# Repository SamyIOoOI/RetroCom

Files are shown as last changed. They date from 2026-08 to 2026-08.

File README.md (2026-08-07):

<h1 align="center">RetroCom</h1>

RetroCom Banner

--------------------------
---------------------------------
## A multiple channel one-to-one (Simultaneous Speech) two-way INTERCOM built around the AT89C52-PI24 MCU // AT89S52-PU24 (8052 Core) with an Embedded FM Radio Model.

### <p align="center">[Main Features](#main-features) **-** [Variations](#variations) **-** [PCB & Schematic](#pcb--schematic-designs) **-** [Assembly Instructions](#-assembly-instructions-) **-** [Case](#case-design) **-** [BOM [Table]](#bill-of-materials) **-** [BOM [CSV]](BOM/BOM.csv) **-** [Gerber Files](/Gerber%20Files/) **-** [BOM[XLSX]](BOM/BOM%20EXCEL.xlsx)</p>

<p align="center">
&nbsp;&nbsp;&nbsp;&nbsp;&nbsp;&nbsp;&nbsp;&nbsp;
</p>

## Main Features

- AT89C52-PI24 MCU per Station. *[Handles Interstation Communication & Interface]*.
- Supports two-way simultaneous speech. No taking turns when talking. RetroCom functions just like a phonecall.
- All stations are connected to main station directly via CAT6 Cables. Distances of 20M (Meters) to 30M are **OK** .
- Switching is done by CD4051 & CD4052 ICs powered with negative & postive 5 V Rails. PreAmped Signals face no distortion.
- Audio undergoes a preamp stage under the TL072 & power amp stage under the LM386.
- The main station has a built in Radio Module. [As of Version 1.0 [WIRED] the radio is restricted to main station with prospects to expand to other stations via HF Radio models in the Wirless versions of RetroCom.]
- All the substations are powered via the Ethernet *(CAT6 if available, other 8 cable variants usable)* No power outlets are needed at the substations.
- Main station supports up to 4 stations in wired mode. Safety measures are applied in the code. No hangs happen when a station is disconnected.
- Code is written in C & compiled with SDCC. Refer to [Station1.hex](station1.hex) & [Station2.hex](station2.hex) for flash-ready code. 

**Be Aware that slight modifications to the code might be required when using different I2C Display modules. Refer to line [35 in main.c](src\main.c) .**

------------------------------------
------------------------------------
## Variations

1- 1.0.0 Wired 2-3-4-Station Package. **[Finished]**:-

- Main station + Station 2 + Station 3 + Station 4
- Code polls for all four stations.
- Main station is connected to the substations via CAT6 Wires.
- Radio control & listen-in is restricted to Station 1 [Main].
- deemed more secure due to the nature of its wired connections.

2- 1.0.0 Wireless 2-30 Station Package [Unfinished]:-
- Planned to dynamically support up to 30 or more stations
- Drops support for CAT6 Wired connections in favor of HF or UHF Radio Transmission.
- Might have security concerns related to signal interception.

-----------------------------------

## PCB & Schematic Designs

The PCB & Schematics were designed in KiCad with a focus on order & accessibility in the case of hand soldering. The RDA5807M [Main Station] is the only SMD Component.``

``All designs follow a two-layer order with the bottom layer functioning as a GND fillzone.``

**== Station 1 [Main Station] [Schematic](KiCad_PCB_Source\RetroCom.kicad_sch) ==**

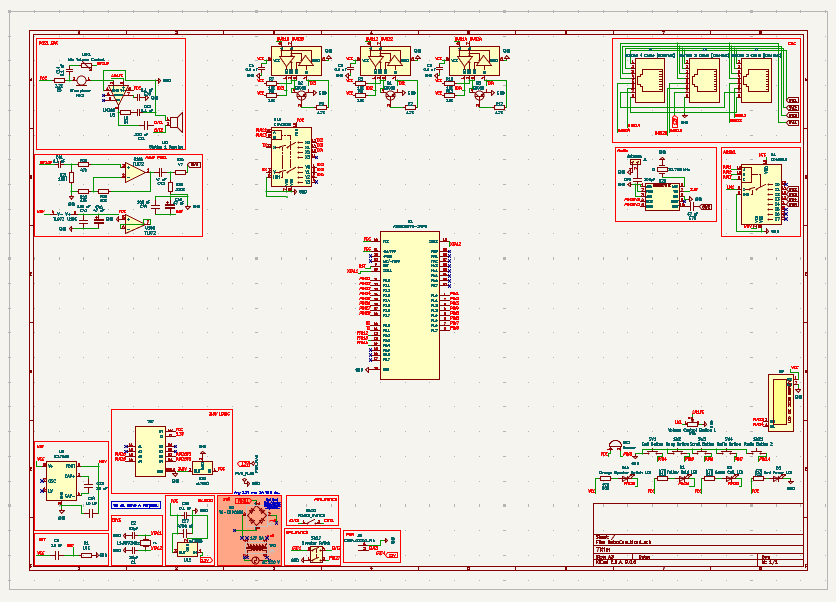
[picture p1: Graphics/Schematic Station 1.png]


**== Station 1 [Main Station] [PCB](KiCad_PCB_Source\RetroCom.kicad_pcb) ==**

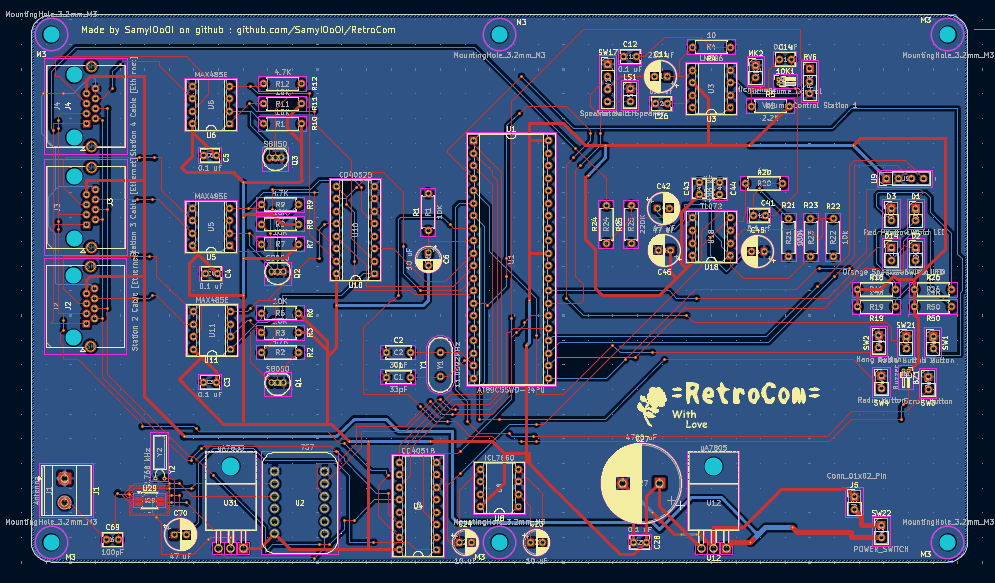
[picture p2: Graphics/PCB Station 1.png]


``3D Model of Board - Uses DIP Sockets Instead of IC Models``

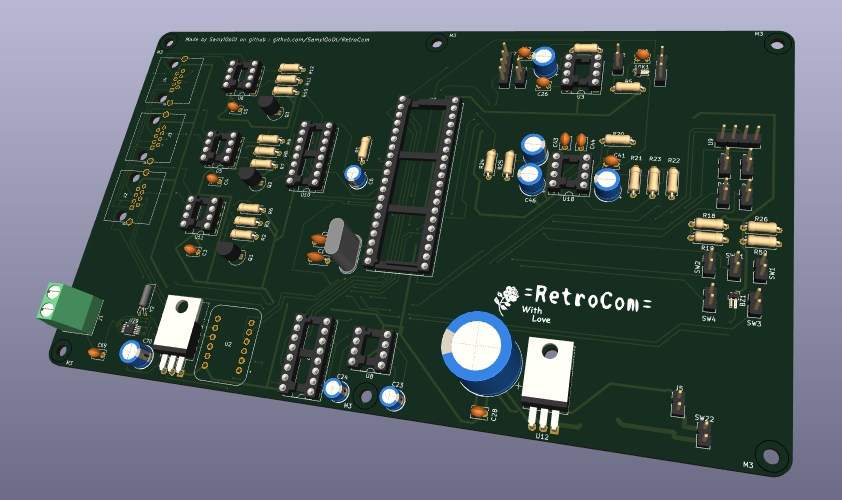
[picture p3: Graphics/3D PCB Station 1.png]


**== Station 2 [Side Station 1] [Schematic](KiCad_PCB_Source\RetroCom_Station2\RetroCom_Station2.kicad_sch) ==**

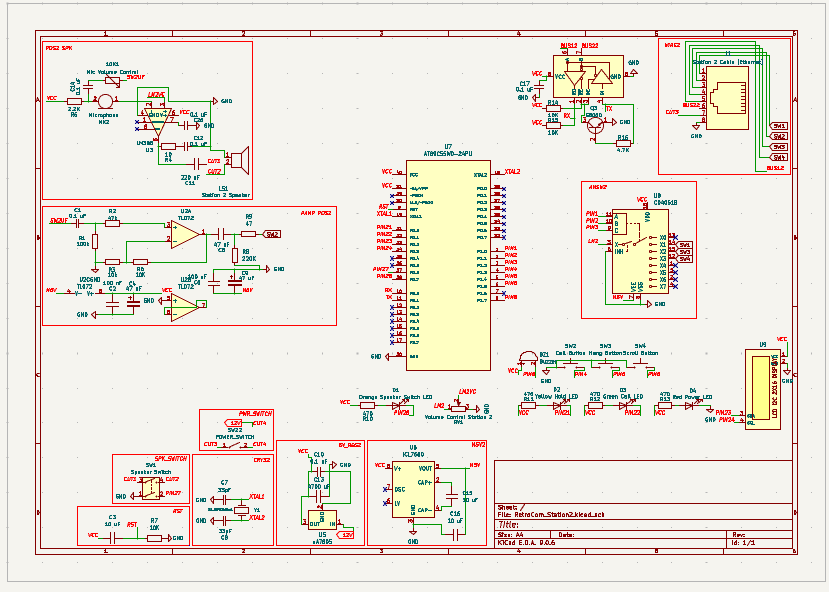
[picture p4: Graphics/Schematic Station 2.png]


**== Station 2 [Side Station 1] [PCB](KiCad_PCB_Source\RetroCom_Station2\RetroCom_Station2.kicad_pcb) ==**

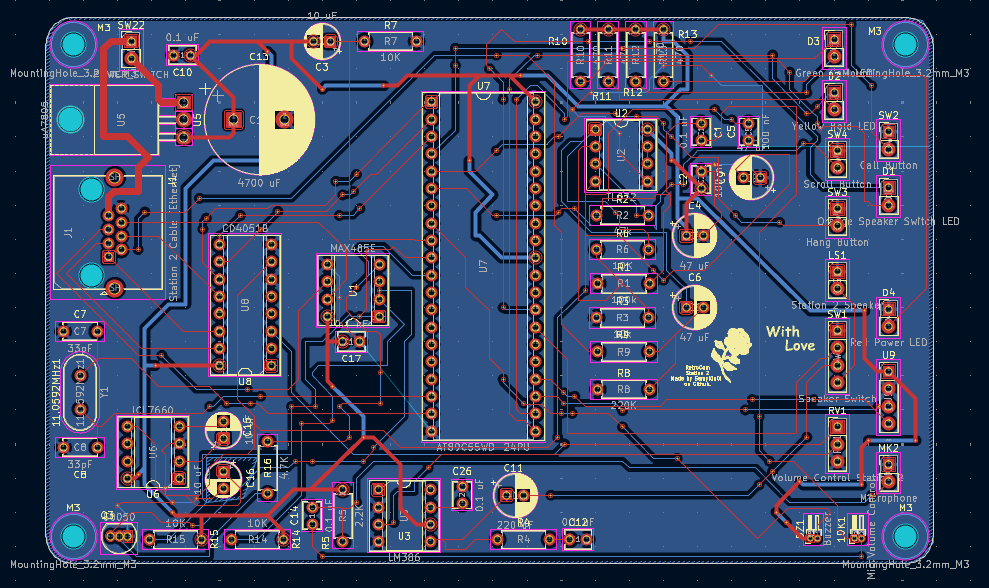
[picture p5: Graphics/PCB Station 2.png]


``3D Model of Board - Uses DIP Sockets Instead of IC Models``

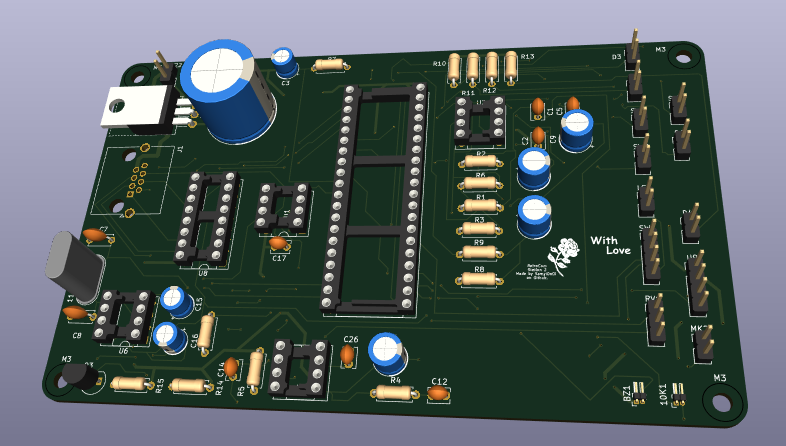
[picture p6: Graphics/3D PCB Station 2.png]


---------------------------------
## Case Design 

The case design was made in fusion with simplicity & practicality in mind.

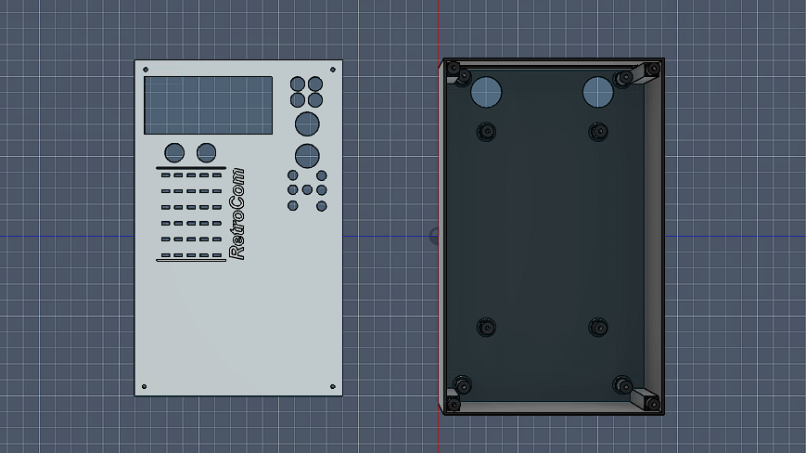
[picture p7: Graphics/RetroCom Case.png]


The design can be accessed via Fusion Share link on your browser through the [link](https://gmail6713823.autodesk360.com/g/shares/SH28cd1QT2badd0ea72b43d7afa1819b979d) provided.

21 x 13 x 5 (cm) are the dimensions of the Case.

---------------------------------
-----------------------------

## = Assembly Instructions =

1- Connecting the PCB & Case

- In the case of **hand-solder** follow the schematic's connections and use the [PCB](Graphics/PCB%20Station%201.png) Design as a reference.
- Use **DIP Sockets** for the ICs (RDA5807M is an exception as it is SMD).
- Connect the ICs & flashed AT89S52s to their respective hand-soldered/printed PCBs.
- Connect the buzzer, speaker, microphone, LEDs, toggle switches, momentary switches & I2C Display through via jumper cables from their respective headers.
- For power, connect half a female jumper wire to the screw terminals of a female DC Socket to wire terminals connector. This can be connected to a **12VDC** 3 & above Amp Wall Adapter.
- Solder the RJ45 Houses in their locations, run CAT6 Cables from each sub-station to main station. 
- For the case, if using the printed design, connect the board to its respective mounting holes via M3 Screws [8mm - 10mm]. 
- Each printed case design has eight board mounting holes to suit both board sizes (Side Stations & Main Station).
- Place the interface components on the surface panel of the case, run jumper cables to the board below. Use the four corner bound M3 screw holes for holding the panel on the bottom case piece. Run the outgoing cables through the back panel.

2- Flashing the code (.hex) files into the AT89S52 Chip.

- Place the AT89 on a breadboard & build the  crystal and reset circuits. Refer to the [Schematic](Graphics/Schematic%20Station%202.png) for details. Look for labels "**CRYS**" & "**RST**".
- Plug the USBasp into you pc/laptop USB port & select it in Zadig's drop-down menu. Install libusb-win32 or libusbK.
- Connect the ISP lines MOSI, MISO, SCK, RESET & GND. EA pin must be connected to VCC. Do not power the circuit before completion.
- Power the circuit through either: A- External 5V Supply B- USBasp's 5V Pinout.
- Use ProgISP to flash the chip. Select AT89S52 from the drop-down menu.

**[ProgISP](https://www.phippselectronics.com/support/prog-isp-software/) Software & [Zadig](https://zadig.akeo.ie/#) Drivers Installer are required to flash the chips.**

## Bill of Materials

| **Part Name** | **Quantity** | **Price** | **Link** |
|---|---|---|---|
| **33pF Capacitor** | 4.00 |  EGP 2.00 | https://makerselectronics.com/product/ceramic-capacitor-33pf-50v/ |
| **10 uF cap** | 6.00 |  EGP 6.00 | https://www.ram-e-shop.com/shop/c-10u25v-capacitor-10uf-25v-6095 |
| **220 uF Cap** | 2.00 |  EGP 2.00 | https://www.ram-e-shop.com/shop/c-220u16v-capacitor-220uf-16v-5654 |
| **4700 uF cap** | 2.00 |  EGP 12.00 | https://www.ram-e-shop.com/shop/c-4700u25v-capacitor-4700uf-25v-6079 |
| **47 uF cap** | 7.00 |  EGP 7.00 | https://makerselectronics.com/product/capacitor-47uf-50v/ |
| **100 nF Cap** | 18.00 |  EGP 13.50 | https://www.ram-e-shop.com/shop/c-pf-104-ceramic-capacitor-pf104-100nf-25v-6240 |
| **100 pF Cap** | 1.00 |  EGP 0.50 | https://makerselectronics.com/product/ceramic-capacitor-100pf-50v/ |
| **Yellow LED  10mm** | 2.00 |  EGP 6.00 | https://makerselectronics.com/product/yellow-led-transparent-10mm/ |
| **Green LED  10mm** | 2.00 |  EGP 6.00 | https://makerselectronics.com/product/green-led-10mm-transparent/ |
| **Red LED  10mm** | 2.00 |  EGP 6.00 | https://makerselectronics.com/product/red-led-transparent-10mm/ |
| **Orange LED  10mm** | 2.00 |  EGP 6.00 | https://makerselectronics.com/product/orange-led-10mm-transparent/ |
| **RJ8-P-PCB (RJ45 8P8C Plastic Housing)** | 5.00 |  EGP 25.00 | https://www.ram-e-shop.com/shop/rj8-p-pcb-rj45-8-pin-connector-on-pcb-plastic-housing-5749 |
| **10K R** | 14.00 |  EGP 4.00 | https://www.ram-e-shop.com/shop/carbon-resistance-1-4w-price-per-4-resistors-9506#attr=314 |
| **2.2K R** | 2.00 |  EGP 0.10 | https://makerselectronics.com/product/carbon-resistor-2-2k%cf%89-0-125w-through-hole/ |
| **10 R** | 2.00 |  EGP 1.50 | https://makerselectronics.com/product/carbon-resistor-10%cf%89-0-25w-through-hole/ |
| **470 R** | 8.00 |  EGP 2.00 | https://www.ram-e-shop.com/shop/carbon-resistance-1-4w-price-per-4-resistors-9506#attr=307 |
| **47k R** | 1.00 |  EGP 1.50 | https://makerselectronics.com/product/carbon-resistor-47k%cf%89-0-25w/ |
| **100k R** | 2.00 |  EGP 1.00 | https://www.ram-e-shop.com/shop/carbon-resistance-1-4w-price-per-4-resistors-9506#attr=317 |
| **47 R** | 2.00 |  EGP 0.20 | https://makerselectronics.com/product/carbon-resistor-47%cf%89-0-125w-through-hole/ |
| **220K R** | 2.00 |  EGP 1.50 | https://makerselectronics.com/product/carbon-resistor-220k%cf%89-0-25w-through-hole/ |
| **4.7K R** | 4.00 |  EGP 1.50 | https://makerselectronics.com/product/carbon-resistor-4-7k-0-25w/ |
| **C8050** | 4.00 |  EGP 3.00 | https://www.ram-e-shop.com/shop/c8050-c8050-6050 |
| **11.0592MHz Crystal** | 2.00 |  EGP 8.00 | https://www.ram-e-shop.com/shop/o-11-0592mhz-crystal-oscillator-11-0592-mhz-5668 |
| **32.768 kHz Crystal** | 1.00 |  EGP 3.00 | https://www.ram-e-shop.com/shop/o-32-768khz-crystal-oscillator-32-768-khz-5880 |
| **PIN Headers x40 Male** | 2.00 |  EGP 6.00 | https://makerselectronics.com/product/pin-headers-male-2-54mm-40-pin-straight-black-11mm/ |
| **PIN Headers x40 Female** | 2.00 |  EGP 10.00 | https://makerselectronics.com/product/pin-headers-female-2-54mm-40-pin/ |
| **Speakers 8 ohm 0.25 watts** | 2.00 |  EGP 20.00 | https://makerselectronics.com/product/speaker-8%cf%89-0-25w-o-29mm/ |
| **Condenser Microphone** | 2.00 |  EGP 12.00 | https://makerselectronics.com/product/condenser-microphone-2-pins/ |
| **I2C LCD 2x16 Modules** | 2.00 |  EGP 290.00 | https://www.ram-e-shop.com/shop/lcd-i2c-2x16-blue-iic-i2c-1602-serial-character-lcd-2x16-display-8884 |
| **4 Pin Toggle Switch DSPT** | 2.00 |  EGP 80.00 | https://makerselectronics.com/product/toggle-switch-4-pins-15a-e-ten1221-o/ |
| **2 Pin Toggle Switch SPST** | 2.00 |  EGP 40.00 | https://makerselectronics.com/product/toggle-switch-on-off-2-pin-2a-12mm/ |
| **Momentary Toggle presses/switches 8** | 8.00 |  EGP 52.00 | https://makerselectronics.com/product/push-button-switch-on-off-2pin/ |
| **Buzzers** | 2.00 |  EGP 50.00 | https://www.ram-e-shop.com/shop/buzzer12v-big-black-buzzer-big-size-3-24v-piezo-electronic-alarm-6122 |
| **PCB 13x25 cm2 Dotted Holes** | 2.00 |  EGP 97.00 | https://www.ram-e-shop.com/shop/pcb23-holes-13x25-pcb-13x25-cm2-dots-holes-sku-pcb23-6681 |
| **Jumper Wire Cables Male to Male [40 Wires]** | 2.00 |  EGP 70.00 | https://www.ram-e-shop.com/shop/ph61-mm-20cm-ph61-20cm-male-to-male-40-jumper-wires-set-7094 |
| **Jumper Wire Cables Female to Female [40 Wires]** | 1.00 |  EGP 35.00 | https://www.ram-e-shop.com/shop/ph62-ff-20cm-ph62-20cm-female-to-female-40-jumper-wires-set-7189 |
| **Jumper Wire Cables Male to Female [40 Wires]** | 2.00 |  EGP 70.00 | https://www.ram-e-shop.com/shop/ph60-mf-20cm-ph60-20cm-male-to-female-40-jumper-wires-set-7066 |
| **Solder Wire** | 1.00 |  EGP 210.00 | https://makerselectronics.com/product/soldering-wire-100gm-alloy70-30-made/ |
| **Soldering Iron** | 1.00 |  EGP 195.00 | https://www.ram-e-shop.com/shop/se860-suoer-se860-60w-basic-soldering-iron-ct-360-5600 |
| **Soldering Iron Stand** | 1.00 |  EGP 45.00 | https://makerselectronics.com/product/no-218-soldering-iron-stand/ |
| **Soldering Paste** | 1.00 |  EGP 25.00 | https://makerselectronics.com/product/yx-18-flux-soldering-paste/?attribute_size=50g |
| **Fares USBasp AVR programmer** | 1.00 |  EGP 175.00 | https://www.ram-e-shop.com/shop/prog-avr-fares-fares-usbasp-avr-programmer-8325 |
| **20 Meter CAT6 Cable** | 1.00 |  EGP 165.00 | https://makerselectronics.com/product/zlink-cable-cat6-ethernet-patch-cord/ |
| **12 VDC Wall Power Adapter** | 1.00 |  EGP 135.00 | https://www.ram-e-shop.com/shop/adapter-fixed-12v-3a-wall-power-adapter-12vdc-3a-high-quality-adapter-5573 |
| **Female DC Jack Adapter with Terminal Block** | 1.00 |  EGP 7.00 | https://makerselectronics.com/product/female-dc-jack-adapter-terminals/ |
| **AT89S52-PU24** | 2.00 |  EGP 170.00 | https://makerselectronics.com/product/at89s52-24pu-8kb-4v5-5v-256byte-24/ |
| **IC Socket DIP-40** | 2.00 |  EGP 10.00 | https://www.ram-e-shop.com/shop/n20-20-ic-socket-n20-20-base-40-pin-5902 |
| **IC Socket DIP-16** | 3.00 |  EGP 5.25 | https://makerselectronics.com/product/ic-socket-88-base-16-pin/ |
| **CD4051** | 2.00 |  EGP 30.00 | https://www.ram-e-shop.com/shop/4051-ic-4051-single-8-channel-multiplexer-demultiplexer-5551 |
| **CD4052BE** | 1.00 |  EGP 9.00 | https://makerselectronics.com/product/cd4052be-dual-4-channel-analog/ |
| **IC Socket DIP-8** | 10.00 |  EGP 7.50 | https://www.ram-e-shop.com/shop/n4-4-ic-socket-n4-4-base-8-pin-5864 |
| **TL072CN** | 2.00 |  EGP 34.00 | https://www.ram-e-shop.com/shop/tl072-tl072cn-5722 |
| **LM386N** | 2.00 |  EGP 12.00 | https://www.ram-e-shop.com/shop/lm386-lm386n-5927 |
| **ICL7660** | 2.00 |  EGP 102.60 | https://uge-one.com/product/icl7660/ |
| **MAX485CPA+** | 4.00 |  EGP 72.00 | https://makerselectronics.com/product/ic-max485cpa-low-power-transceiver-dip-8/ |
| **LM7805 Regulator** | 2.00 |  EGP 10.00 | https://makerselectronics.com/product/lm7805-voltage-regulator-to-220-5v/ |
| **LD33CV Regulator** | 1.00 |  EGP 20.00 | https://www.ram-e-shop.com/shop/ld1117v33-ld1117v33-ld33cv-6735 |
| **TO-220 Regulator Heat Sink** | 3.00 |  EGP 10.50 | https://www.ram-e-shop.com/shop/hs2-aluminum-heatsink-hs-2-size-25x14x10-mm-5981 |
| **Logic level Converter Module** | 1.00 |  EGP 28.50 | https://uge-one.com/product/bi-directional-4-way-level-conversion-module/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 |
| **Metal Potentiometer 10K? 3-Pin** | 2.00 |  EGP 11.00 | https://makerselectronics.com/product/metal-potentiometer-10k%cf%89-3-pin/ |
| **RDA5807M** | 1.00 |  EGP 55.00 | https://uge-one.com/product/rda5807m-fm-radio-receiver-smd-ic-msop1 |
| **** | |  EGP 2,495.65  | |
| **** | | | |
| **Note: Most resistors come in pack of 10s - 4s**  | | | |
| **** | | | |
| **Shipping: RAM** | |  EGP 105.00 | |
| **Shipping: Makers Electronics** | 80 - 75 |  EGP 80.00 | |
| **Shipping: UGE Electronics** | |  EGP 188.10 | |
| **VAT: UGE Electronics** | |  EGP 45.95 | |
| **** | |  EGP 419.05 | |
| **** | | | |
| **** | |  EGP 2,914.70  | |

## Credits

[Kicad](https://www.kicad.org/) : Schematic & PCB designs

[Autodesk Fusion](https://www.autodesk.com/ae/products/fusion-360/overview) : 3D Case Design

[Visual Studio Code](https://code.visualstudio.com/) : Logic Code Design

[Embedded IDE For VSCode](https://em-ide.com/en/) : Compiling C files into .hex format

[Notaroomba Cyberboard](https://github.com/notaroomba/cyberboard#key-features) : Inspired readme format

[tableconvert.com](https://tableconvert.com/excel-to-markdown) : Turned my xlsx table to markdown format

## Licence

Made by SamyIOoOI on github under the GPL-3.0 Licence.

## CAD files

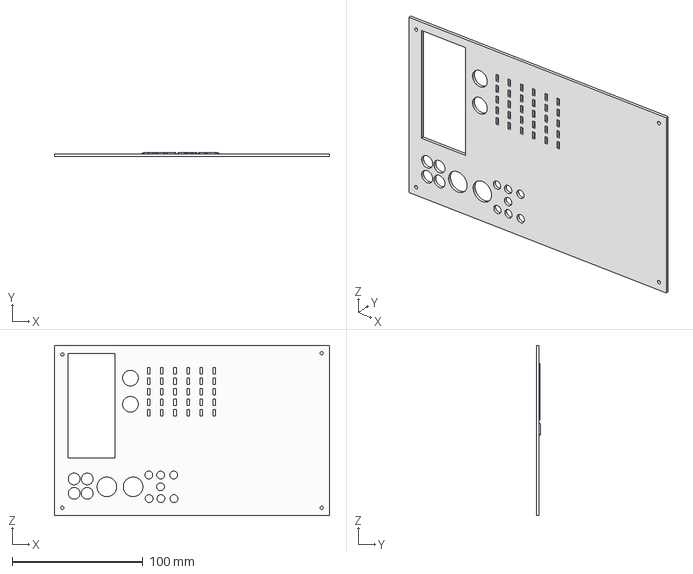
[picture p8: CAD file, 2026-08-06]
Fusion_Case_Cad/RetroCom Case CAD/RetroCom Case Top.step
210.0 x 3.00 x 130.0 mm

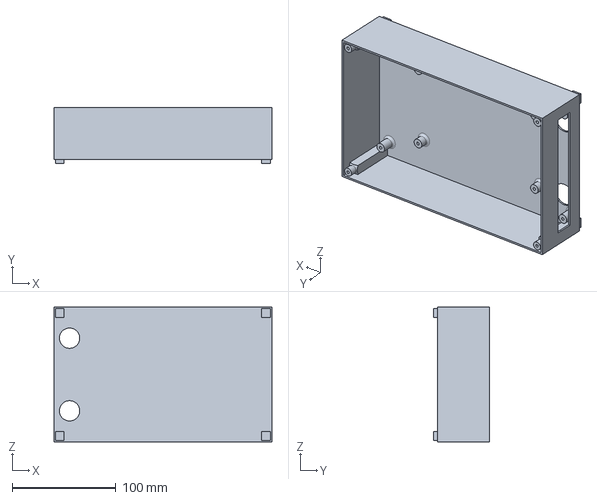
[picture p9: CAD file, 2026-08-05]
Fusion_Case_Cad/RetroCom Case CAD/RetroCom Case Bottom.step
210.0 x 53.5 x 130.0 mm

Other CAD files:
Fusion_Case_Cad/RetroCom Case CAD/RetroCom Case Bottom.f3d
Fusion_Case_Cad/RetroCom Case CAD/RetroCom Case Bottom.stl
Fusion_Case_Cad/RetroCom Case CAD/RetroCom Case Top.f3d
Fusion_Case_Cad/RetroCom Case CAD/RetroCom Case Top.stl

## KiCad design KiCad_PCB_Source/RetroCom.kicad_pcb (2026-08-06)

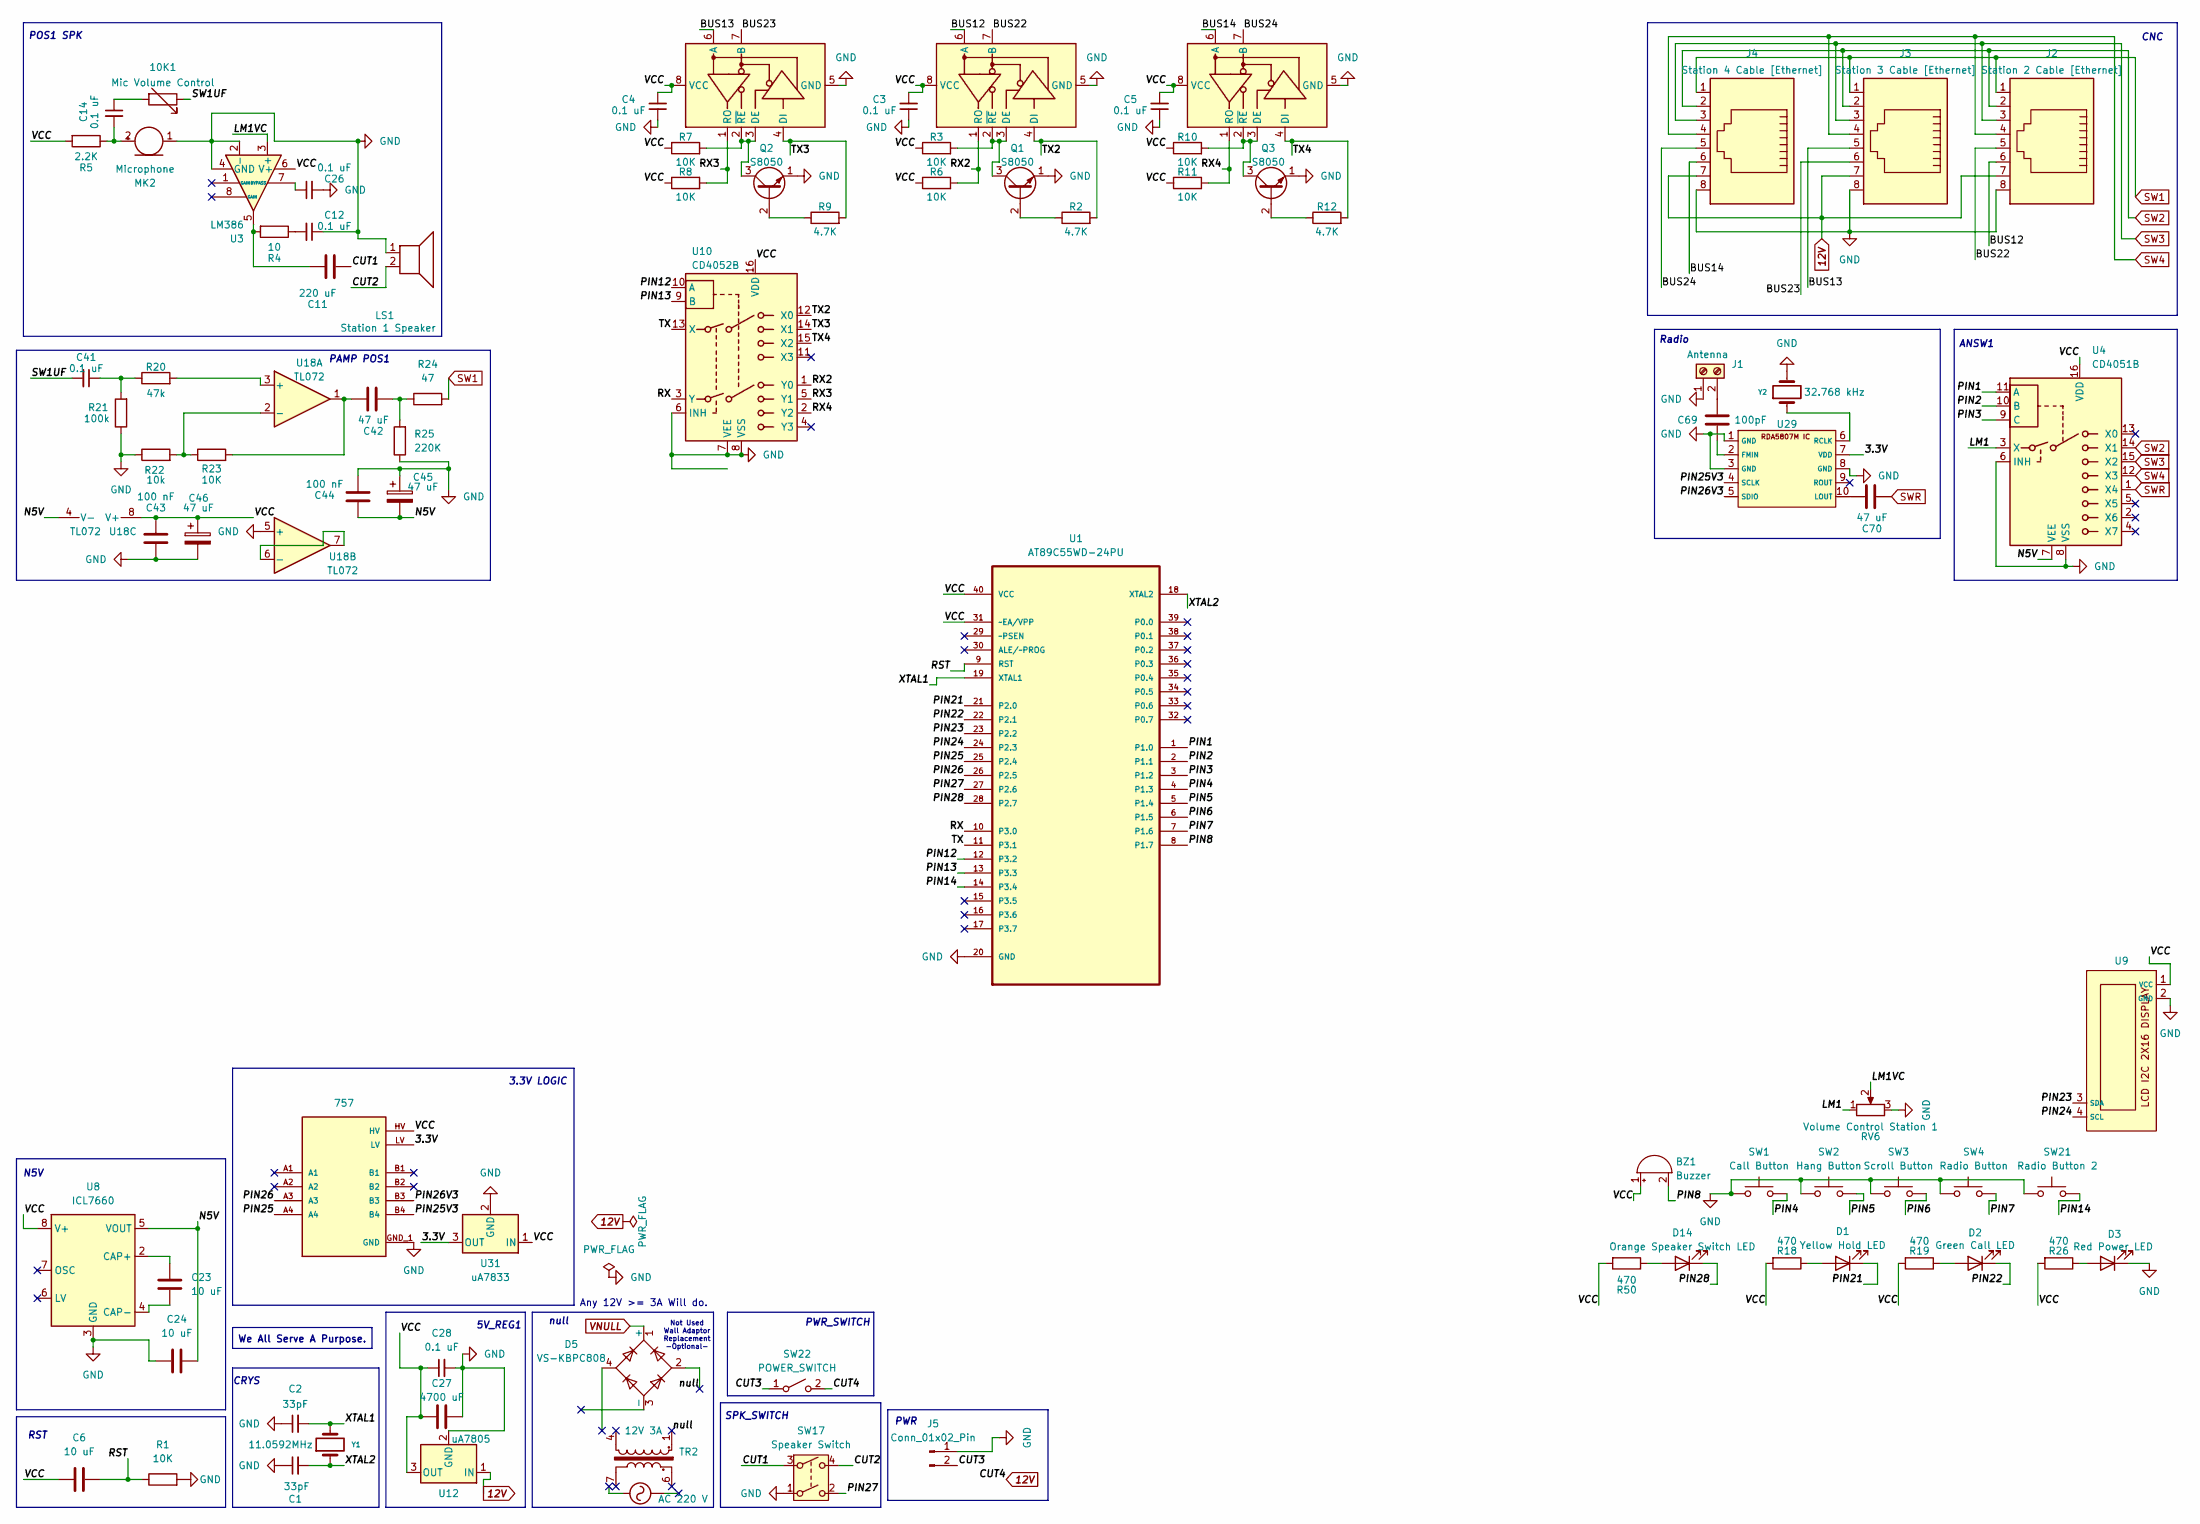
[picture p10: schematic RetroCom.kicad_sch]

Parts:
10K1: Mic Volume Control; PinHeader_1x02_P1.00mm_Horizontal
BZ1: Buzzer; PinHeader_1x02_P1.00mm_Horizontal
C1, C2: 33pF; C_Disc_D5.0mm_W2.5mm_P5.00mm
C3, C4, C5, C12, C14, C26, C28, C41: 0.1 uF; C_Disc_D3.8mm_W2.6mm_P2.50mm
C6, C23, C24: 10 uF; CP_Radial_D5.0mm_P2.50mm
C11: 220 uF; CP_Radial_D6.3mm_P2.50mm
C27: 4700 uF; CP_Radial_D16.0mm_P7.50mm
C42, C45, C46, C70: 47 uF; CP_Radial_D6.3mm_P2.50mm
C43, C44: 100 nF; C_Disc_D3.8mm_W2.6mm_P2.50mm
C69: 100pF; C_Disc_D3.8mm_W2.6mm_P2.50mm
D1: Yellow Hold LED; PinHeader_1x02_P2.54mm_Vertical
D2: Green Call LED; PinHeader_1x02_P2.54mm_Vertical
D3: Red Power LED; PinHeader_1x02_P2.54mm_Vertical
D5: VS-KBPC808; Diode_Bridge_Vishay_KBPC6
D14: Orange Speaker Switch LED; PinHeader_1x02_P2.54mm_Vertical
J1: Antenna; TerminalBlock_Phoenix_MKDS-1,5-2_1x02_P5.00mm_Horizontal
J2: Station 2 Cable [Ethernet]; RJ45_Amphenol_RJHSE5380
J3: Station 3 Cable [Ethernet]; RJ45_Amphenol_RJHSE5380
J4: Station 4 Cable [Ethernet]; RJ45_Amphenol_RJHSE5380
J5: Conn_01x02_Pin; PinHeader_1x02_P2.54mm_Vertical
LS1: Station 1 Speaker; PinHeader_1x02_P2.54mm_Vertical
MK2: Microphone; PinHeader_1x02_P2.54mm_Vertical
Q1, Q2, Q3: S8050; TO-92_Inline
R1, R3, R6, R7, R8, R10, R11, R23: 10K; R_Axial_DIN0207_L6.3mm_D2.5mm_P7.62mm_Horizontal
R2, R9, R12: 4.7K; R_Axial_DIN0207_L6.3mm_D2.5mm_P7.62mm_Horizontal
R4: 10; R_Axial_DIN0207_L6.3mm_D2.5mm_P7.62mm_Horizontal
R5: 2.2K; R_Axial_DIN0207_L6.3mm_D2.5mm_P7.62mm_Horizontal
R18, R19, R26, R50: 470; R_Axial_DIN0207_L6.3mm_D2.5mm_P7.62mm_Horizontal
R20: 47k; R_Axial_DIN0207_L6.3mm_D2.5mm_P7.62mm_Horizontal
R21: 100k; R_Axial_DIN0207_L6.3mm_D2.5mm_P7.62mm_Horizontal
R22: 10k; R_Axial_DIN0207_L6.3mm_D2.5mm_P7.62mm_Horizontal
R24: 47; R_Axial_DIN0207_L6.3mm_D2.5mm_P7.62mm_Horizontal
R25: 220K; R_Axial_DIN0207_L6.3mm_D2.5mm_P7.62mm_Horizontal
RV6: Volume Control Station 1; PinHeader_1x03_P2.54mm_Vertical
SW1: Call Button; PinHeader_1x02_P2.54mm_Vertical
SW2: Hang Button; PinHeader_1x02_P2.54mm_Vertical
SW3: Scroll Button; PinHeader_1x02_P2.54mm_Vertical
SW4: Radio Button; PinHeader_1x02_P2.54mm_Vertical
SW17: Speaker Switch; PinHeader_1x04_P2.54mm_Vertical
SW21: Radio Button 2; PinHeader_1x02_P2.54mm_Vertical
SW22: POWER_SWITCH; PinHeader_1x02_P2.54mm_Vertical
TR2: 12V 3A; FanPinHeader_1x04_P2.54mm_Vertical
U1: AT89C55WD-24PU; DIP-40_W15.24mm_Socket; MPN AT89C55WD-24PU
U2: 757; MODULE_757; PARTREV N/A
U3: LM386; DIP-8_W7.62mm_Socket
U4: CD4051B; DIP-16_W7.62mm_Socket
U5, U6, U11: MAX485E; DIP-8_W7.62mm_Socket
U8: ICL7660; DIP-8_W7.62mm_Socket
U9: PinHeader_1x04_P2.54mm_Vertical
U10: CD4052B; DIP-16_W7.62mm_Socket
U12: uA7805; TO-220-3_Horizontal_TabUp
U18: TL072; DIP-8_W7.62mm_Socket
U29: MSOP-10_3x3mm_P0.5mm
U31: uA7833; TO-220-3_Horizontal_TabUp
Y1: 11.0592MHz; Crystal_HC49-U_Vertical
Y2: 32.768 kHz; Crystal_C26-LF_D2.1mm_L6.5mm_Horizontal

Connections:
12V: J2.7, J3.7, J4.7, SW22.2 (B), U12.1 (IN)
/3.3V: U2.LV, U29.7 (VDD), U31.3 (OUT)
/BUS12: J2.6, U11.6 (A)
/BUS13: J3.5, U5.6 (A)
/BUS14: J4.6, U6.6 (A)
/BUS22: J2.5, U11.7 (B)
/BUS23: J3.6, U5.7 (B)
/BUS24: J4.5, U6.7 (B)
/CUT1: C11.2, SW17.3
/CUT2: LS1.2, SW17.4
/CUT3: J5.2, SW22.1 (A)
/LM1: RV6.1, U4.3 (X)
/LM1VC: RV6.2, U3.3 (+)
/N5V: C24.1, C44.2, C45.2, U4.7 (VEE), U8.5 (VOUT), U18.4 (V-)
/PIN1: U1.1 (P1.0), U4.11 (A)
/PIN2: U1.2 (P1.1), U4.10 (B)
/PIN3: U1.3 (P1.2), U4.9 (C)
/PIN4: SW1.2, U1.4 (P1.3)
/PIN5: SW2.2, U1.5 (P1.4)
/PIN6: SW3.2, U1.6 (P1.5)
/PIN7: SW4.2, U1.7 (P1.6)
/PIN8: BZ1.2 (-), U1.8 (P1.7)
/PIN12: U1.12 (P3.2), U10.10 (A)
/PIN13: U1.13 (P3.3), U10.9 (B)
/PIN14: SW21.2, U1.14 (P3.4)
/PIN21: D1.1 (K), U1.21 (P2.0)
/PIN22: D2.1 (K), U1.22 (P2.1)
/PIN23: U1.23 (P2.2), U9.3 (SDA)
/PIN24: U1.24 (P2.3), U9.4 (SCL)
/PIN25: U1.25 (P2.4), U2.A4
/PIN25V3: U2.B4, U29.4 (SCLK)
/PIN26: U1.26 (P2.5), U2.A3
/PIN26V3: U2.B3, U29.5 (SDIO)
/PIN27: SW17.2, U1.27 (P2.6)
/PIN28: D14.1 (K), U1.28 (P2.7)
/RST: C6.1, R1.1, U1.9 (RST)
/RX: U1.10 (P3.0), U10.3 (Y)
/RX2: R6.2, U10.1 (Y0), U11.1 (RO)
/RX3: R8.2, U5.1 (RO), U10.5 (Y1)
/RX4: R11.2, U6.1 (RO), U10.2 (Y2)
/SW1UF: 10K1.1, C41.2
/TX: U1.11 (P3.1), U10.13 (X)
/TX2: R2.2, U10.12 (X0), U11.4 (DI)
/TX3: R9.2, U5.4 (DI), U10.14 (X1)
/TX4: R12.2, U6.4 (DI), U10.15 (X2)
/VCC: BZ1.1 (+), C3.2, C4.2, C5.2, C6.2, C27.1, C28.1, C43.1, C46.1, R3.1, R5.2, R6.1, R7.1, R8.1, R10.1, R11.1, R18.2, R19.2, R26.2, R50.2, U1.31 (~EA/VPP), U1.40 (VCC), U2.HV, U3.6 (V+), U4.16 (VDD), U5.8 (VCC), U6.8 (VCC), U8.8 (V+), U9.1 (VCC), U10.16 (VDD), U11.8 (VCC), U12.3 (OUT), U18.8 (V+), U31.1 (IN)
/XTAL1: C2.2, U1.19 (XTAL1), Y1.2
/XTAL2: C1.2, U1.18 (XTAL2), Y1.1
GND: C1.1, C2.1, C3.1, C4.1, C5.1, C12.1, C24.2, C26.2, C27.2, C28.2, C43.2, C44.1, C45.1, C46.2, D3.1 (K), J1.1, J2.8, J3.8, J4.8, J5.1, LS1.1, MK2.1 (-), Q1.1 (E), Q2.1 (E), Q3.1 (E), R1.2, R21.1, R22.1, R25.1, RV6.3, SW1.1, SW2.1, SW3.1, SW4.1, SW17.1, SW21.1, U1.20 (GND), U2.GND_1 (GND), U2.GND_2 (GND), U3.2 (-), U3.4 (GND), U4.6 (INH), U4.8 (VSS), U5.5 (GND), U6.5 (GND), U8.3 (GND), U9.2 (GND), U10.6 (INH), U10.7 (VEE), U10.8 (VSS), U11.5 (GND), U12.2 (GND), U18.5 (+), U29.1 (GND), U29.3 (GND), U29.8 (GND), U31.2 (GND), Y2.2
unnamed: 10K1.2, C14.1
unnamed: C11.1, R4.2, U3.5
unnamed: C12.2, R4.1
unnamed: C41.1, R20.1, R21.2
unnamed: C42.1, R23.2, U18.1
unnamed: C42.2, R24.1, R25.2
unnamed: D1.2 (A), R18.1
unnamed: D2.2 (A), R19.1
unnamed: D3.2 (A), R26.1
unnamed: D5.2, TR2.1
unnamed: D14.2 (A), R50.1
unnamed: C69.1, J1.2
unnamed: C14.2, MK2.2 (+), R5.1
unnamed: Q1.2 (B), R2.1
unnamed: Q1.3 (C), R3.2, U11.2 (~RE), U11.3 (DE)
unnamed: Q2.2 (B), R9.1
unnamed: Q2.3 (C), R7.2, U5.2 (~RE), U5.3 (DE)
unnamed: Q3.2 (B), R12.1
unnamed: Q3.3 (C), R10.2, U6.2 (~RE), U6.3 (DE)
unnamed: C26.1, U3.7 (BYPASS)
unnamed: C23.1, U8.2 (CAP+)
unnamed: C23.2, U8.4 (CAP-)
unnamed: R20.2, U18.3 (+)
unnamed: R22.2, R23.1, U18.2 (-)
unnamed: U18.6 (-), U18.7
unnamed: C69.2, U29.2 (FMIN)
unnamed: C70.1, U29.10 (LOUT)
unnamed: U29.6 (RCLK), Y2.1
SW1: J2.1, J3.1, J4.1, R24.2
SW2: J2.2, J3.2, J4.2, U4.14 (X1)
SW3: J2.3, J3.3, J4.3, U4.15 (X2)
SW4: J2.4, J3.4, J4.4, U4.12 (X3)
SWR: C70.2, U4.1 (X4)

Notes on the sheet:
3.3V LOGIC
We All Serve A Purpose.
Radio
CNC
POS1 SPK
5V_REG1
PWR
PWR_SWITCH
RST
Not Used Wall Adaptor Replacement -Optional-
ANSW1
SPK_SWITCH
N5V
CRYS
PAMP POS1
null
Any 12V >= 3A Will do.

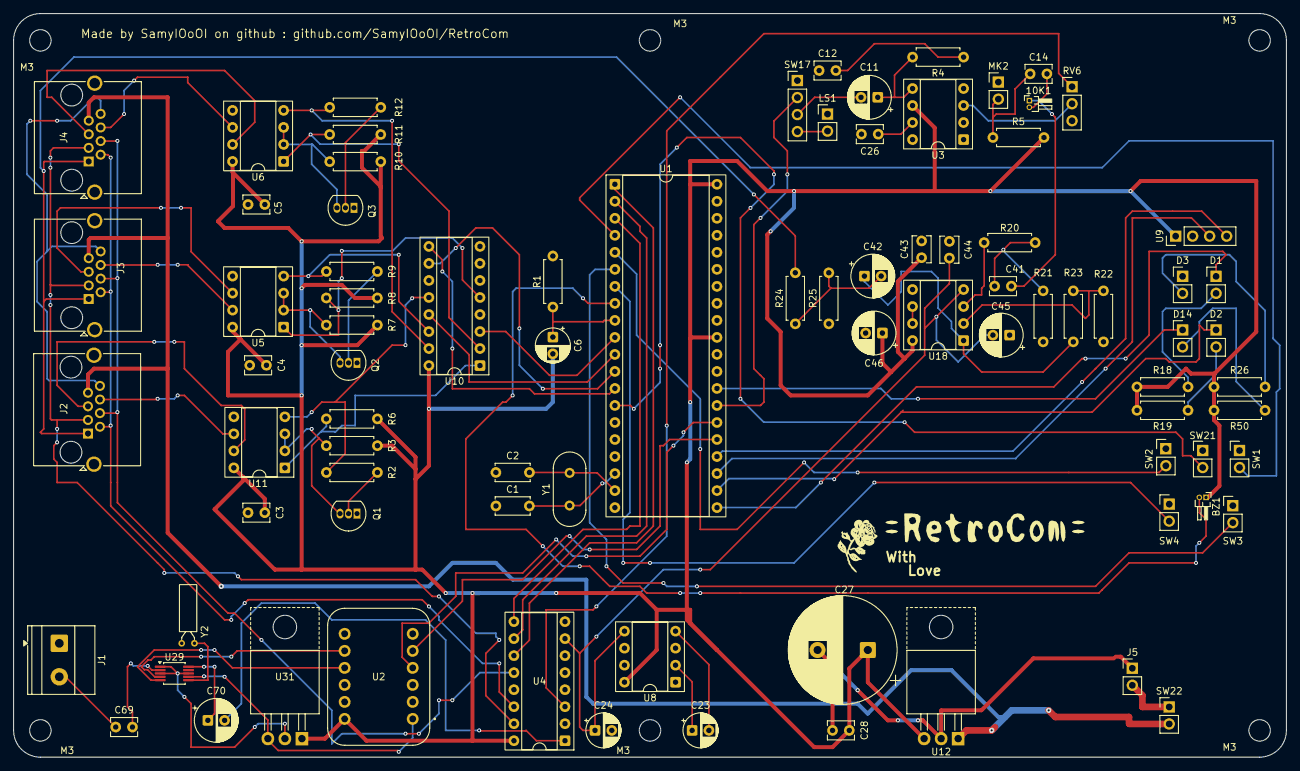
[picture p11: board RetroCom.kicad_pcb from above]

Board: 2 copper layers, 190.0 x 111.0 mm, 90 parts (0 on the bottom side), 81 nets.

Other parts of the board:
M3, M3#2, M3#3, M3#4, M3#5, M3#6: MountingHole_3.2mm_M3

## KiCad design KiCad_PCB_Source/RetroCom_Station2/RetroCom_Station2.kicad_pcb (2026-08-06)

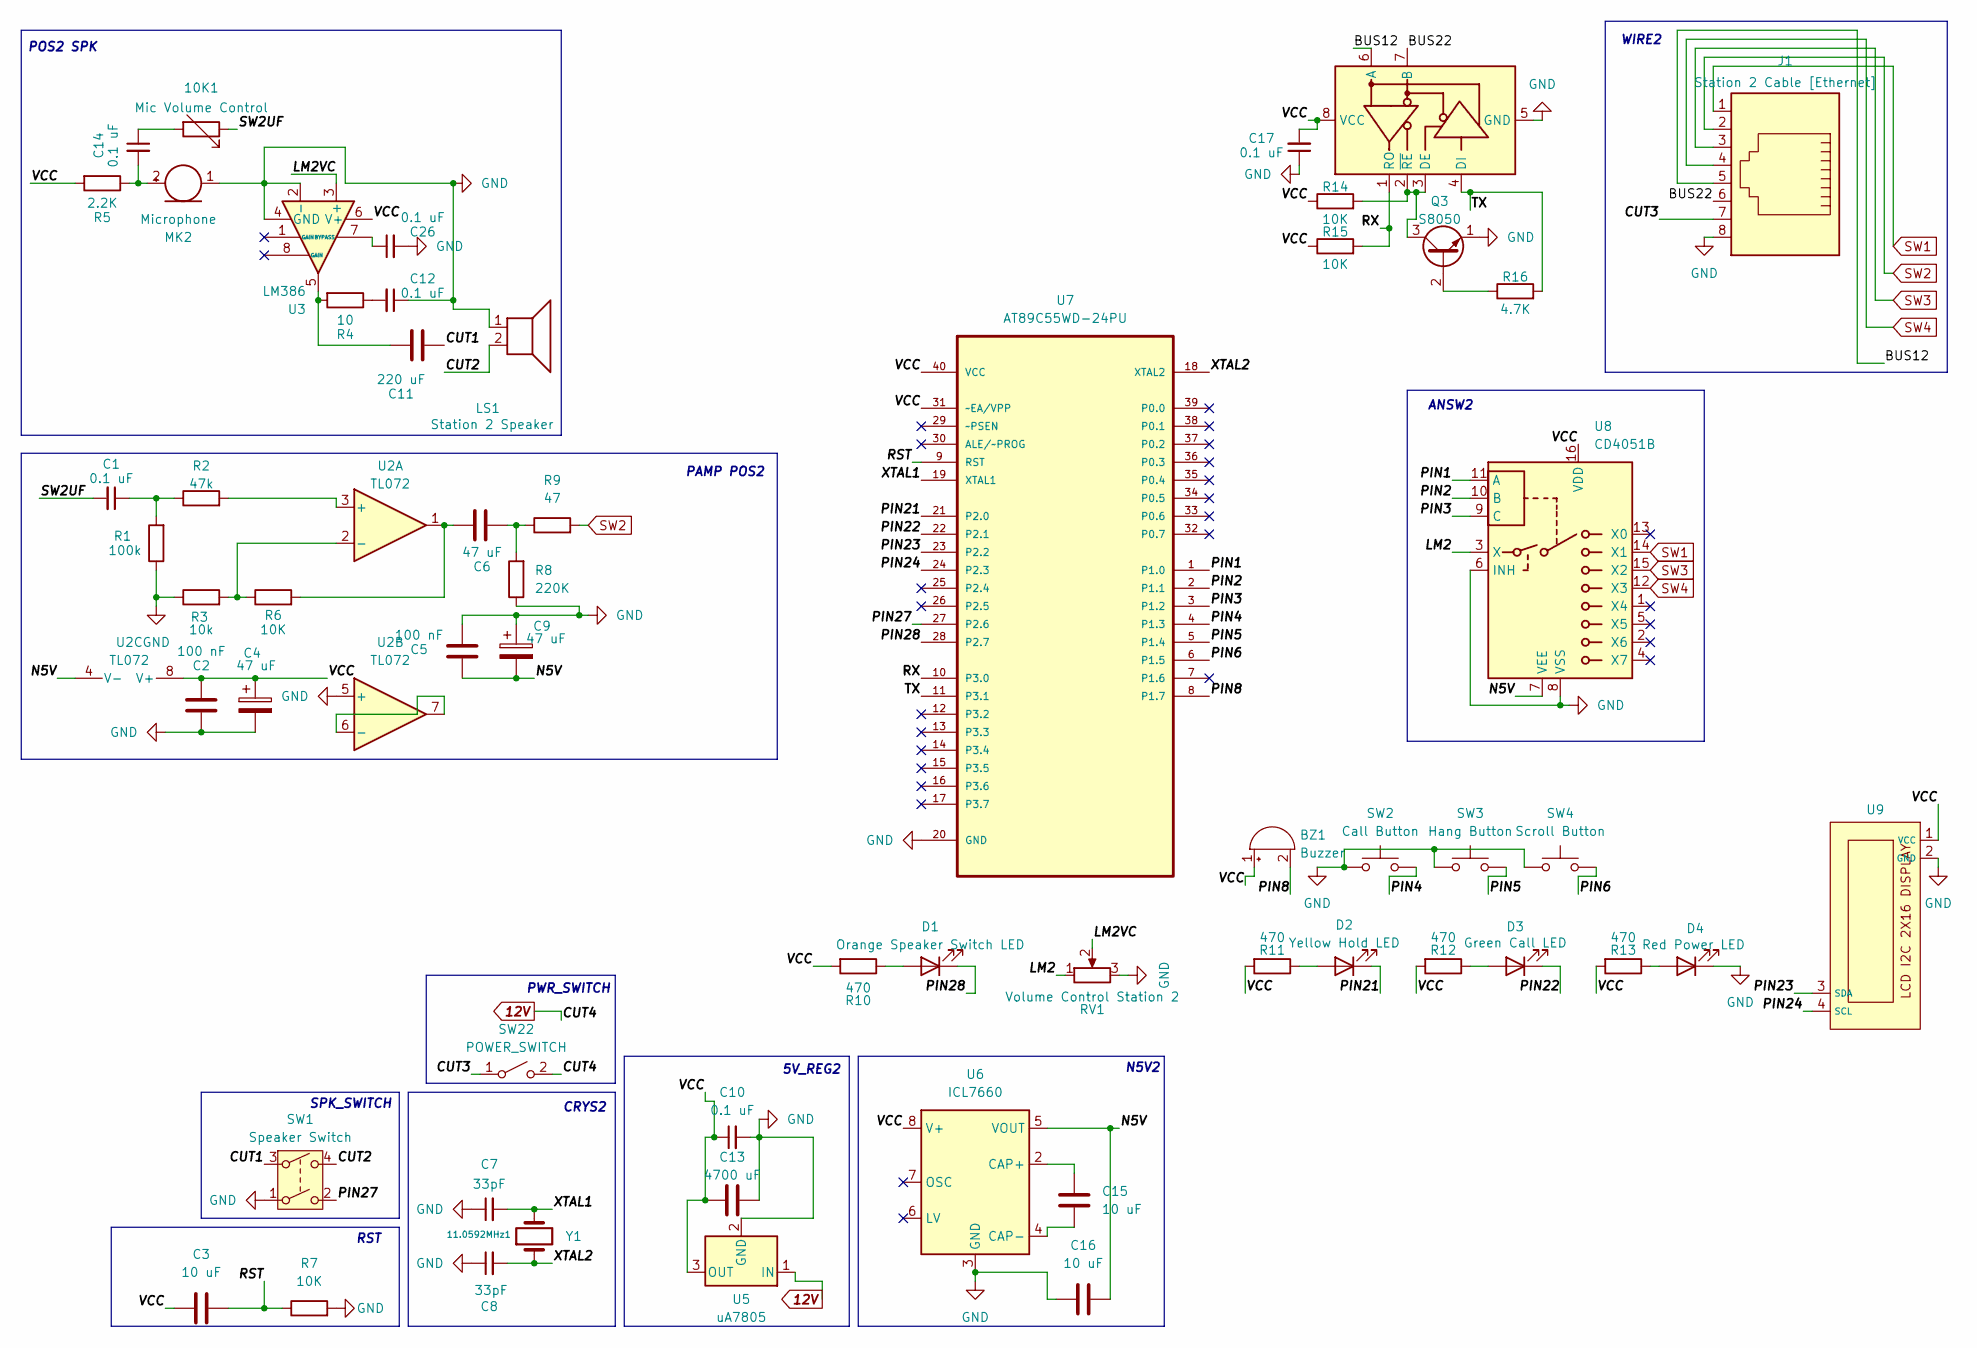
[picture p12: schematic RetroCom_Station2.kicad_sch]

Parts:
10K1: Mic Volume Control; PinHeader_1x02_P1.00mm_Horizontal
11.0592MHz1: Y1; Crystal_HC49-U_Vertical
BZ1: Buzzer; PinHeader_1x02_P1.00mm_Horizontal
C1, C10, C12, C14, C17, C26: 0.1 uF; C_Disc_D3.8mm_W2.6mm_P2.50mm
C2, C5: 100 nF; C_Disc_D3.8mm_W2.6mm_P2.50mm
C3, C15, C16: 10 uF; CP_Radial_D5.0mm_P2.50mm
C4, C6, C9: 47 uF; CP_Radial_D6.3mm_P2.50mm
C7, C8: 33pF; C_Disc_D5.0mm_W2.5mm_P5.00mm
C11: 220 uF; CP_Radial_D6.3mm_P2.50mm
C13: 4700 uF; CP_Radial_D16.0mm_P7.50mm
D1: Orange Speaker Switch LED; PinHeader_1x02_P2.54mm_Vertical
D2: Yellow Hold LED; PinHeader_1x02_P2.54mm_Vertical
D3: Green Call LED; PinHeader_1x02_P2.54mm_Vertical
D4: Red Power LED; PinHeader_1x02_P2.54mm_Vertical
J1: Station 2 Cable [Ethernet]; RJ45_Amphenol_RJHSE5380
LS1: Station 2 Speaker; PinHeader_1x02_P2.54mm_Vertical
MK2: Microphone; PinHeader_1x02_P2.54mm_Vertical
Q3: S8050; TO-92_Inline
R1: 100k; R_Axial_DIN0207_L6.3mm_D2.5mm_P7.62mm_Horizontal
R2: 47k; R_Axial_DIN0207_L6.3mm_D2.5mm_P7.62mm_Horizontal
R3: 10k; R_Axial_DIN0207_L6.3mm_D2.5mm_P7.62mm_Horizontal
R4: 10; R_Axial_DIN0207_L6.3mm_D2.5mm_P7.62mm_Horizontal
R5: 2.2K; R_Axial_DIN0207_L6.3mm_D2.5mm_P7.62mm_Horizontal
R6, R7, R14, R15: 10K; R_Axial_DIN0207_L6.3mm_D2.5mm_P7.62mm_Horizontal
R8: 220K; R_Axial_DIN0207_L6.3mm_D2.5mm_P7.62mm_Horizontal
R9: 47; R_Axial_DIN0207_L6.3mm_D2.5mm_P7.62mm_Horizontal
R10, R11, R12, R13: 470; R_Axial_DIN0207_L6.3mm_D2.5mm_P7.62mm_Horizontal
R16: 4.7K; R_Axial_DIN0207_L6.3mm_D2.5mm_P7.62mm_Horizontal
RV1: Volume Control Station 2; PinHeader_1x03_P2.54mm_Vertical
SW1: Speaker Switch; PinHeader_1x04_P2.54mm_Vertical
SW2: Call Button; PinHeader_1x02_P2.54mm_Vertical
SW3: Hang Button; PinHeader_1x02_P2.54mm_Vertical
SW4: Scroll Button; PinHeader_1x02_P2.54mm_Vertical
SW22: POWER_SWITCH; PinHeader_1x02_P2.54mm_Vertical
U1: MAX485E; DIP-8_W7.62mm_Socket
U2: TL072; DIP-8_W7.62mm_Socket
U3: LM386; DIP-8_W7.62mm_Socket
U5: uA7805; TO-220-3_Horizontal_TabUp
U6: ICL7660; DIP-8_W7.62mm_Socket
U7: AT89C55WD-24PU; DIP-40_W15.24mm_Socket; MPN AT89C55WD-24PU
U8: CD4051B; DIP-16_W7.62mm_Socket
U9: PinHeader_1x04_P2.54mm_Vertical

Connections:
12V: SW22.2 (B), U5.1 (IN)
/BUS12: J1.5, U1.6 (A)
/BUS22: J1.6, U1.7 (B)
/CUT1: C11.2, SW1.3
/CUT2: LS1.2, SW1.4
/CUT3: J1.7, SW22.1 (A)
/LM2: RV1.1, U8.3 (X)
/LM2VC: RV1.2, U3.3 (+)
/N5V: C5.2, C9.2, C16.1, U2.4 (V-), U6.5 (VOUT), U8.7 (VEE)
/PIN1: U7.1 (P1.0), U8.11 (A)
/PIN2: U7.2 (P1.1), U8.10 (B)
/PIN3: U7.3 (P1.2), U8.9 (C)
/PIN4: SW2.2, U7.4 (P1.3)
/PIN5: SW3.2, U7.5 (P1.4)
/PIN6: SW4.2, U7.6 (P1.5)
/PIN8: BZ1.2 (-), U7.8 (P1.7)
/PIN21: D2.1 (K), U7.21 (P2.0)
/PIN22: D3.1 (K), U7.22 (P2.1)
/PIN23: U7.23 (P2.2), U9.3 (SDA)
/PIN24: U7.24 (P2.3), U9.4 (SCL)
/PIN27: SW1.2, U7.27 (P2.6)
/PIN28: D1.1 (K), U7.28 (P2.7)
/RST: C3.1, R7.1, U7.9 (RST)
/RX: R15.2, U1.1 (RO), U7.10 (P3.0)
/SW2UF: 10K1.1, C1.2
/TX: R16.2, U1.4 (DI), U7.11 (P3.1)
/VCC: BZ1.1 (+), C2.1, C3.2, C4.1, C10.1, C13.1, C17.2, R5.2, R10.2, R11.2, R12.2, R13.2, R14.1, R15.1, U1.8 (VCC), U2.8 (V+), U3.6 (V+), U5.3 (OUT), U6.8 (V+), U7.31 (~EA/VPP), U7.40 (VCC), U8.16 (VDD), U9.1 (VCC)
/XTAL1: 11.0592MHz1.2, C7.2, U7.19 (XTAL1)
/XTAL2: 11.0592MHz1.1, C8.2, U7.18 (XTAL2)
GND: C2.2, C4.2, C5.1, C7.1, C8.1, C9.1, C10.2, C12.1, C13.2, C16.2, C17.1, C26.2, D4.1 (K), J1.8, LS1.1, MK2.1 (-), Q3.1 (E), R1.1, R3.1, R7.2, R8.1, RV1.3, SW1.1, SW2.1, SW3.1, SW4.1, U1.5 (GND), U2.5 (+), U3.2 (-), U3.4 (GND), U5.2 (GND), U6.3 (GND), U7.20 (GND), U8.6 (INH), U8.8 (VSS), U9.2 (GND)
unnamed: 10K1.2, C14.1
unnamed: C1.1, R1.2, R2.1
unnamed: C6.1, R6.2, U2.1
unnamed: C6.2, R8.2, R9.1
unnamed: C11.1, R4.2, U3.5
unnamed: C12.2, R4.1
unnamed: D1.2 (A), R10.1
unnamed: D2.2 (A), R11.1
unnamed: D3.2 (A), R12.1
unnamed: D4.2 (A), R13.1
unnamed: C14.2, MK2.2 (+), R5.1
unnamed: Q3.2 (B), R16.1
unnamed: Q3.3 (C), R14.2, U1.2 (~RE), U1.3 (DE)
unnamed: R2.2, U2.3 (+)
unnamed: R3.2, R6.1, U2.2 (-)
unnamed: U2.6 (-), U2.7
unnamed: C26.1, U3.7 (BYPASS)
unnamed: C15.1, U6.2 (CAP+)
unnamed: C15.2, U6.4 (CAP-)
SW1: J1.1, U8.14 (X1)
SW2: J1.2, R9.2
SW3: J1.3, U8.15 (X2)
SW4: J1.4, U8.12 (X3)

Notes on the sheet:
PAMP POS2
PWR_SWITCH
CRYS2
POS2 SPK
5V_REG2
SPK_SWITCH
WIRE2
ANSW2
N5V2
RST

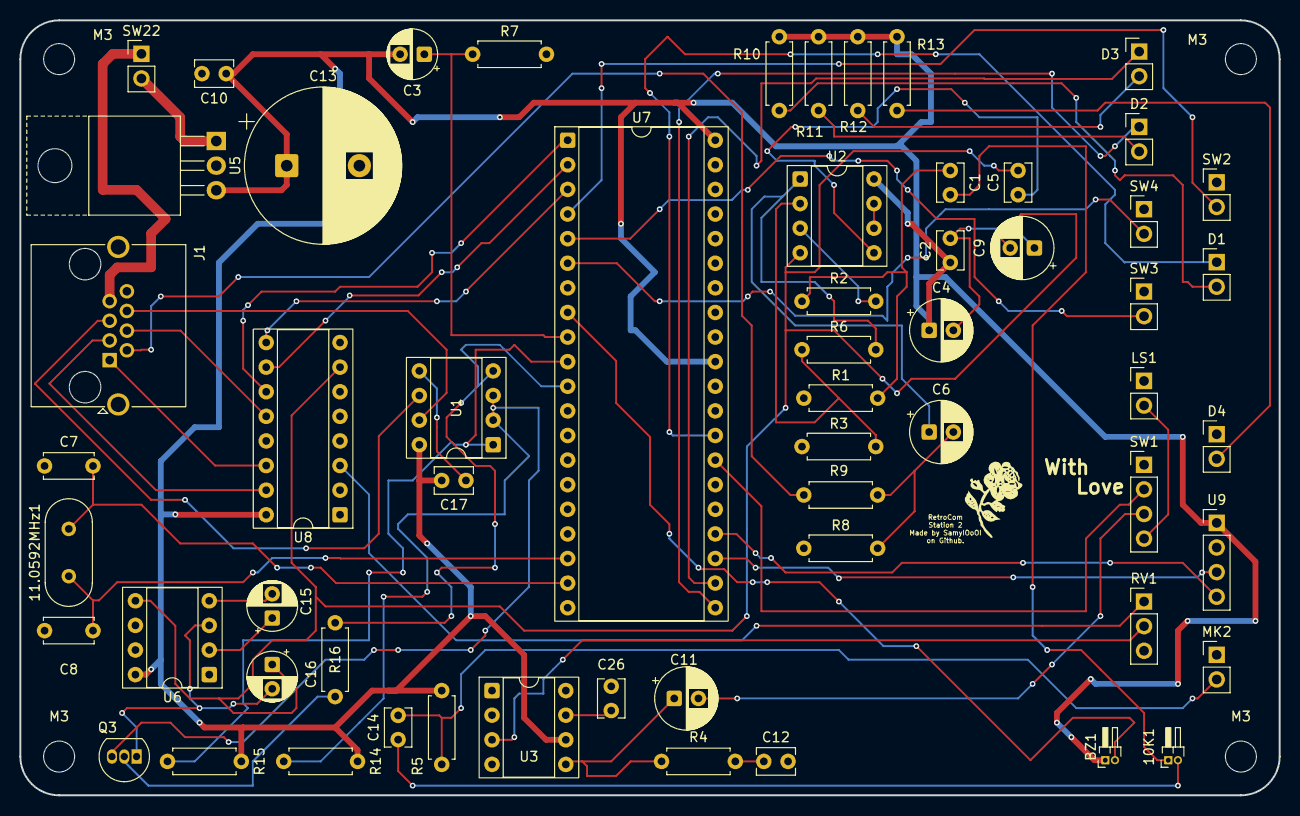
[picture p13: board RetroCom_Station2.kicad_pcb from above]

Board: 2 copper layers, 130.0 x 80.0 mm, 63 parts (0 on the bottom side), 53 nets.

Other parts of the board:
M3, M3#2, M3#3, M3#4: MountingHole_3.2mm_M3

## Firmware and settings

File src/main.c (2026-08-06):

/**
 * CPU: 89C52
 * Freq: 11.0592Mhz
*/

#include <reg52.h>
#include <stdio.h>
/* #include <intrins.h> */
#define _nop_() __asm__("nop")

__sbit __at (0x90) CDBUS1; 
__sbit __at (0x91) CDBUS2;
__sbit __at (0x92) CDBUS3;
__sbit __at (0x93) CALL_BTN;
__sbit __at (0x94) HANG_BTN;
__sbit __at (0x95) SCROLL_BTN;
__sbit __at (0x96) RADIO_BTN1;
__sbit __at (0xB4) RADIO_BTN2;
__sbit __at (0x97) BUZZER;
__sbit __at (0xA0) YELLOW_LED;
__sbit __at (0xA1) GREEN_LED;
__sbit __at (0xA2) SDA_DISPLAY;
__sbit __at (0xA3) SCL_DISPLAY;
__sbit __at (0xA4) RADIO_SCLK;
__sbit __at (0xA5) RADIO_SDIO;
__sbit __at (0xA6) SPK_SWITCH_STATUS;
__sbit __at (0xA7) ORANGE_LED;
__sbit __at (0xB0) RX_PIN;
__sbit __at (0xB1) TX_PIN;
__sbit __at (0xB2) ST_CD_A;
__sbit __at (0xB3) ST_CD_B;



#define I2C_DISPLAY_ADDR 0x4E /*I gotta change this based on my I2C Address*/
#define I2C_RADIO_ADDR 0x20 /*I gotta change this based on my I2C Address*/


void I2C_Delay(void);
void LCD_START(void);
void LCD_STOP(void);
void LCD_Write(unsigned char dat);
void LCD_Nibble(unsigned char nibble, unsigned char iscontrol);
void LCD_Send(unsigned char value, unsigned char iscontrol);
void LCD_CMD(unsigned char cmd);
void LCD_Letter(unsigned char letter);
void LCD_Sentence(unsigned char *sentence);
void cursor(unsigned char row, unsigned char col);
void Radio_Start(void);
void Radio_Stop(void);
void Radio_Write(unsigned char dat);
void radio_registery(unsigned char upper, unsigned char lower);
void Radio_Process(unsigned char r2_high, unsigned char r2_low, unsigned char r3_high, unsigned char r3_low);
void Set_Radio(unsigned char mode);
void select_station_poll(unsigned char station);
void Poller(void);
void unpacker(void);
void pack_poll_byte(unsigned char call, unsigned char call_target, unsigned char end_call, unsigned char busy, unsigned char decline, unsigned char trgt_busy);
void UART_Send(unsigned char dot2);
unsigned char UART_Read(unsigned char timeout_limit);
void Init_UART(void);
void Init_System(void);
void Init_Display(void);
void LISTEN_STATION2(void);
void LISTEN_STATION3(void);
void LISTEN_STATION4(void);
void LISTEN_RADIO(void);
void LISTEN_NONE(void);
void calldisplay(void);
void endcall(void);
void incoming(void);

volatile unsigned char timer = 0;
volatile unsigned char poll = 0x00;
volatile unsigned char selected_station = 2;
volatile unsigned char recieved_message = 0;

bit Is_Speaker_On = 1;
bit selected_mode = 0;
bit Is_Display_Busy = 0;
bit incoming_call = 0;
bit outgoing_call = 0;
bit buzzer_flag = 0;
unsigned char selected_radio_station = 0;
unsigned char Busy_Display_Clock = 0;
unsigned char who_main_wants = 0;
unsigned char ring_start_time = 0;
volatile unsigned char seconds = 0;
volatile unsigned int ms_time = 0;
unsigned char buzzer_clock = 0;

/* Master Station Section (The state of all stations is stored here) */

bit station1_busy = 0;
bit station2_busy = 0;
bit station3_busy = 0;
bit station4_busy = 0;
bit radio_on = 0;

unsigned char station1_calltrgt = 0;
unsigned char station2_calltrgt = 0;
unsigned char station3_calltrgt = 0;
unsigned char station4_calltrgt = 0;

unsigned char station1_calling = 0;
unsigned char station2_calling = 0;
unsigned char station3_calling = 0;
unsigned char station4_calling = 0;

bit station1_on = 1;
bit station2_on = 1;
bit station3_on = 1;
bit station4_on = 1;

bit station1_rcall = 0;
bit station2_rcall = 0;
bit station3_rcall = 0;
bit station4_rcall = 0;

bit end_call_recieved1 = 0;
bit end_call_recieved2 = 0;
bit end_call_recieved3 = 0;
bit end_call_recieved4 = 0;

bit station1_decline = 0;
bit station2_decline = 0;
bit station3_decline = 0;
bit station4_decline = 0;

bit station1_trgtbusy = 0;
bit station1_accept = 0;
bit station2_accept = 0;
bit station3_accept = 0;
bit station4_accept = 0;

bit send_accept_station1 = 0;
bit send_accept_station2 = 0;
bit send_accept_station3 = 0;
bit send_accept_station4 = 0;


/*///*/
unsigned char currently_polling = 2;

void LCD_Nibble(unsigned char nibble, unsigned char iscontrol) {
    unsigned char data_value = (nibble & 0x0F) | (iscontrol ? 0x01 : 0x00) | 0x08;
    LCD_START();
    LCD_Write(I2C_DISPLAY_ADDR);
    LCD_Write(data_value | 0x04);
    I2C_Delay();
    LCD_Write(data_value & ~0x04);
    LCD_STOP();
}
void LCD_Send(unsigned char value, unsigned char iscontrol) {
    LCD_Nibble((value & 0xF0), iscontrol);
    LCD_Nibble((value << 4) & 0xF0, iscontrol);
}
void LCD_CMD(unsigned char cmd){
    LCD_Send(cmd, 0);
}
void LCD_Letter(unsigned char letter){
    LCD_Send(letter, 1);
}
void LCD_Sentence(unsigned char *sentence){
    while(*sentence){
        LCD_Letter(*sentence++);
    }
}
void select_station_poll(unsigned char station){
    if(station == 2) {
        ST_CD_A = 0;
        ST_CD_B = 0;
        _nop_();
        _nop_();
    }
    else if (station == 3){
        ST_CD_A = 0;
        ST_CD_B = 1;
        _nop_();
        _nop_();
    }
    else if (station == 4){
        ST_CD_A = 1;
        ST_CD_B = 0;
        _nop_();
        _nop_();
    }
}
void Poller(void){
    unsigned char call_1 = 0; 
    unsigned char call_target_1 = 0;
    unsigned char end_call_1 = 0;
    unsigned char busy_1 = 0;
    unsigned char decline_1 = 0;
    unsigned char accept_1 = 0;
    if (currently_polling == 2) {
        select_station_poll(2);
        if (station2_rcall){
            if (station2_calltrgt == 3) {
                if (station3_busy) {
                    decline_1 = 1;
                }
                if (station3_decline) {
                    decline_1 = 1;
                    station3_decline = 0;
                }
            
            }
            if (station2_calltrgt == 4){
                if (station4_busy) {
                    decline_1 = 1;
                }
                if (station4_decline) {
                    decline_1 = 1;
                    station4_decline = 0;
                }
            }
            if (station2_calltrgt == 1) {
                if (station1_busy) {
                    decline_1 = 1;
                }
                if (station1_decline) {
                    decline_1 = 1;
                    station1_decline = 0;
                }
            }
        }
        if (station3_calltrgt == 2 && station3_rcall) {
            call_1 = 1;
            call_target_1 = 3;
        }
        else if (station4_calltrgt == 2 && station4_rcall) {
            call_1 = 1;
            call_target_1 = 4;
        }
        else if (station1_calltrgt == 2 && station1_rcall) {
            call_1 = 1;
            call_target_1 = 1; 
        }
        if (station2_calling == 1 && end_call_recieved1){
            end_call_recieved1 = 0;
            station2_calling = 0;
            station1_calling = 0;
            station1_busy = 0;
            end_call_1 = 1;
            station1_calltrgt = 0;
            station1_rcall = 0;
            station2_busy = 0;
        }
        if (station2_calling == 3 && end_call_recieved3){
            end_call_recieved3 = 0;
            station3_calling = 0;
            station2_calling = 0;
            station3_busy = 0;
            end_call_1 = 1;
            station3_calltrgt = 0;
            station3_rcall = 0;
            station2_busy = 0;
        }
        if (station2_calling == 4 && end_call_recieved4){
            end_call_recieved4 = 0;
            station4_calling = 0;
            station2_calling = 0;
            station4_busy = 0;
            end_call_1 = 1;
            station4_calltrgt = 0;
            station4_rcall = 0;
            station2_busy = 0;
        }
        if (station3_rcall && (station3_calltrgt == 2) && station2_accept){
            station3_rcall = 0;
            station3_calling = 2;
            station2_calling = 3;
            station3_busy = 1;
            send_accept_station3 = 1;
        }
        else if (station4_rcall && (station4_calltrgt == 2) && station2_accept){
            station4_rcall = 0;
            station4_calling = 2;
            station2_calling = 4;
            station4_busy = 1;
            send_accept_station4 = 1;
        }
        else if (station1_rcall && (station1_calltrgt == 2) && station2_accept){
            station1_rcall = 0;
            station1_calling = 2;
            station2_calling = 1;
            station1_busy = 1;
            send_accept_station1 = 1;
        }
        if (send_accept_station2){
            send_accept_station2 = 0;
            accept_1 = 1;
            if (station2_calltrgt == 1){
                station1_busy = 1;
                incoming_call = 0;
            }
            else if (station2_calltrgt == 3){
                station3_busy = 1;
            }
            else if (station2_calltrgt == 4){
                station4_busy = 1;
            }
        }
    }
    if (currently_polling == 3) {
        select_station_poll(3);
        if (station3_rcall){
            if (station3_calltrgt == 2) {
                if (station2_busy) {
                    decline_1 = 1;
                }
                if (station2_decline) {
                    decline_1 = 1;
                    station2_decline = 0;
                }
            
            }
            if (station3_calltrgt == 4){
                if (station4_busy) {
                    decline_1 = 1;
                }
                if (station4_decline) {
                    decline_1 = 1;
                    station4_decline = 0;
                }
            }
            if (station3_calltrgt == 1) {
                if (station1_busy) {
                    decline_1 = 1;
                }
                if (station1_decline) {
                    decline_1 = 1;
                    station1_decline = 0;
                }
            }
        }
        if (station2_calltrgt == 3 && station2_rcall) {
            call_1 = 1;
            call_target_1 = 3;
        }
        else if (station4_calltrgt == 3 && station4_rcall) {
            call_1 = 1;
            call_target_1 = 4;
        }
        else if (station1_calltrgt == 3 && station1_rcall) {
            call_1 = 1;
            call_target_1 = 1; 
        }
        if (station3_calling == 1 && end_call_recieved1){
            end_call_recieved1 = 0;
            station3_calling = 0;
            station1_calling = 0;
            station1_busy = 0;
            end_call_1 = 1;
            station1_calltrgt = 0;
            station1_rcall = 0;
            station3_busy = 0;
        }
        if (station3_calling == 2 && end_call_recieved2){
            end_call_recieved2 = 0;
            station3_calling = 0;
            station2_calling = 0;
            station2_busy = 0;
            end_call_1 = 1;
            station2_calltrgt = 0;
            station2_rcall = 0;
            station3_busy = 0;
        }
        if (station3_calling == 4 && end_call_recieved4){
            end_call_recieved4 = 0;
            station4_calling = 0;
            station3_calling = 0;
            station4_busy = 0;
            end_call_1 = 1;
            station4_calltrgt = 0;
            station4_rcall = 0;
            station3_busy = 0;
        }
        if (station2_rcall && (station2_calltrgt == 3) && station3_accept){
            station2_rcall = 0;
            station2_calling = 3;
            station3_calling = 2;
            station2_busy = 1;
            send_accept_station2 = 1;
        }
        else if (station4_rcall && (station4_calltrgt == 3) && station3_accept){
            station4_rcall = 0;
            station4_calling = 3;
            station3_calling = 4;
            station4_busy = 1;
            send_accept_station4 = 1;
        }
        else if (station1_rcall && (station1_calltrgt == 3) && station3_accept){
            station1_rcall = 0;
            station1_calling = 3;
            station3_calling = 1;
            station1_busy = 1;
            send_accept_station1 = 1;
        }
        if (send_accept_station3){
            send_accept_station3 = 0;
            accept_1 = 1;
            if (station3_calltrgt == 1){
                station1_busy = 1;
                incoming_call = 0;
            }
            else if (station3_calltrgt == 2){
                station2_busy = 1;
            }
            else if (station3_calltrgt == 4){
                station4_busy = 1;
            }
        }
    }
    if (currently_polling == 4) {
        select_station_poll(4);
        if (station4_rcall){
            if (station4_calltrgt == 3) {
                if (station3_busy) {
                    decline_1 = 1;
                }
                if (station3_decline) {
                    decline_1 = 1;
                    station3_decline = 0;
                }
            
            }
            if (station4_calltrgt == 2){
                if (station2_busy) {
                    decline_1 = 1;
                }
                if (station2_decline) {
                    decline_1 = 1;
                    station2_decline = 0;
                }
            }
            if (station4_calltrgt == 1) {
                if (station1_busy) {
                    decline_1 = 1;
                }
                if (station1_decline) {
                    decline_1 = 1;
                    station1_decline = 0;
                }
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
void main(void)
{
    unsigned char x = 0;
    unsigned char y = 0;
    unsigned char busy_display_clock = 0;
    bit last_state_scroll_btn = 1;
    bit last_state_call_btn = 1;
    bit last_state_hang_btn = 1;
    bit last_state_radio_btn1 = 1;
    bit last_state_radio_btn2 = 1;
    bit current_state_scroll_btn = 1;
    bit current_state_call_btn = 1;
    bit current_state_hang_btn = 1;
    bit current_state_radio_btn1 = 1;
    bit current_state_radio_btn2 = 1;

    Init_System();
    Init_UART();
    Init_Display();

    while(1) {
        if ((unsigned char)(timer - x) >= 20) {
            x = timer;
            station1_on = Is_Speaker_On;
            current_state_scroll_btn = SCROLL_BTN;
            current_state_call_btn = CALL_BTN;
            current_state_hang_btn = HANG_BTN;
            current_state_radio_btn1 = RADIO_BTN1;
            current_state_radio_btn2 = RADIO_BTN2;
            if (SPK_SWITCH_STATUS == 0) {
                ORANGE_LED = 0;
                Is_Speaker_On = 1;
            }
            else if (SPK_SWITCH_STATUS == 1) {
                ORANGE_LED = 1;
                Is_Speaker_On = 0;
            }
            if (buzzer_flag){
                if ((unsigned char)(seconds - buzzer_clock) >= 1){
                    buzzer_clock = seconds; 
                    BUZZER = !BUZZER;
                }
            }
            else if (!buzzer_flag){
                BUZZER = 1;
            }
            if (Is_Display_Busy){
                if ((unsigned char)(timer - busy_display_clock) >= 75){
                    Is_Display_Busy = 0;
                    cursor(2, 1);
                    LCD_Sentence("St:0");
                    selected_station = 0;
                }
            }
            if ((station1_calling == 2 && station2_calling == 1) || 
            (station1_calling == 3 && station3_calling == 1) || 
            (station1_calling == 4 && station4_calling == 1)){
                station1_busy = 1;
                YELLOW_LED = 1;
            }
            if (station1_calltrgt) {
                if (station1_calltrgt == 2){
                    if (station2_accept){
                        station1_calling = 2;
                        station2_calling = 1;
                        station1_busy = 1;
                        station1_calltrgt = 0;
                        YELLOW_LED = 1;
                        GREEN_LED = 0;
                        LISTEN_STATION2();
                        calldisplay();
                    }
                    else if (station2_decline){
                        station1_calltrgt = 0;
                        station2_decline = 0;
                        YELLOW_LED = 1;
                        endcall();
                    }
                }
                else if (station1_calltrgt == 3){
                    if (station3_accept){
                        station1_calling = 3;
                        station3_calling = 1;
                        station1_busy = 1;
                        station1_calltrgt = 0;
                        YELLOW_LED = 1;
                        GREEN_LED = 0;
                        LISTEN_STATION3();
                        calldisplay();
                    }
                    else if (station3_decline){
                        station1_calltrgt = 0;
                        station3_decline = 0;
                        YELLOW_LED = 1;
                        endcall();
                    }
                }
                else if (station1_calltrgt == 4){
                    if (station4_accept){
                        station1_calling = 4;
                        station4_calling = 1;
                        station1_busy = 1;
                        station1_calltrgt = 0;
                        YELLOW_LED = 1;
                        GREEN_LED = 0;
                        LISTEN_STATION4();
                        calldisplay();
                    }
                    else if (station4_decline){
                        station1_calltrgt = 0;
                        station4_decline = 0;
                        YELLOW_LED = 1;
                        endcall();
                    }
                }
            }
            if (station1_calling){
                if (station1_calling == 2){
                    if (end_call_recieved2){
                        end_call_recieved2 = 0;
                        station1_calling = 0;
                        station2_calling = 0;
                        station1_busy = 0;
                        endcall();
                    }
                }
                else if (station1_calling == 3){
                    if (end_call_recieved3){
                        end_call_recieved3 = 0;
                        station1_calling = 0;
                        station3_calling = 0;
                        station1_busy = 0;
                        endcall();
                    }
                }
                else if (station1_calling == 4){
                    if (end_call_recieved4){
                        end_call_recieved4 = 0;
                        station1_calling = 0;
                        station4_calling = 0;
                        station1_busy = 0;
                        endcall();
                    }
                }
            }
            if (station2_calltrgt == 1 && station2_rcall && !station1_busy && !incoming_call){
                selected_station = 2;
                incoming();
            }
            else if (station3_calltrgt == 1 && station3_rcall && !station1_busy && !incoming_call){
                selected_station = 3;
                incoming();    
            }
            else if (station4_calltrgt == 1 && station4_rcall && !station1_busy && !incoming_call){
                selected_station = 4;
                incoming();
            }
                /* If all stations call station 1 
                (or station x later when I copy this to
                 the other statios local code) 
                 Priority is 1>2>3>4 */
            if (((station2_calltrgt == 1 && station2_rcall) ||
             (station3_calltrgt == 1 && station3_rcall) ||
             (station4_calltrgt == 1 && station4_rcall)) 
             && station1_accept){
                if (who_main_wants == 2){
                    station1_calling = 2;
                    station1_accept = 0;
                    station2_calling = 1;
                    send_accept_station2 = 1;
                    calldisplay();
                    LISTEN_STATION2();
                }
                else if (who_main_wants == 3){
                    station1_calling = 3;
                    station1_accept = 0;
                    station3_calling = 1;
                    send_accept_station3 = 1;
                    calldisplay();
                    LISTEN_STATION3();
                }
                else if (who_main_wants == 4){
                    station1_calling = 4;
                    station1_accept = 0;
                    station4_calling = 1;
                    send_accept_station4 = 1;
                    calldisplay();
                    LISTEN_STATION4();
                }
             }
            if (send_accept_station1){
                send_accept_station1 = 0;
                station1_rcall = 0;
                station1_calling = station1_calltrgt;
                GREEN_LED = 0;
                if (station1_calltrgt == 2){
                    LISTEN_STATION2();
                    calldisplay();
                }
                else if (station1_calltrgt == 3){
                    LISTEN_STATION3();
                    calldisplay();
                }
                else if (station1_calltrgt == 4){
                    LISTEN_STATION4();
                    calldisplay();
                }
            }
            if (station1_rcall && (!station1_busy || !station1_calling ) ){
                if ((unsigned char)(seconds - ring_start_time) >= 45){
                    station1_rcall = 0;
                    station1_calltrgt = 0;
                    YELLOW_LED = 1;
                    endcall();
                }
            }
            if (incoming_call && (!station1_busy || !station1_calling)){
                if ((unsigned char)(seconds - ring_start_time) >= 45){
                    incoming_call = 0;
                    buzzer_flag = 0;
                    YELLOW_LED = 1;
                    endcall();
                }
            }
            if (current_state_scroll_btn == 0 && last_state_scroll_btn == 1 && !station1_busy && !incoming_call && !outgoing_call) {
                if (selected_mode == 0) {
                    if (selected_station == 0){
                        selected_station = 2;
                        cursor(2, 4);
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

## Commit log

2026-07-26 added the main structure of the main station's code (station 1) and the basic I2C functions for the RDA and the Display chips + the button polling
    note: IM MOVING THE ZEROS HANK IM MOVING ZEROS AND ONES
2026-07-27 the display data and command functions via i2c bitbanging
2026-07-27 began to construct the station state variables, added the radio modes and controls, added display modes and controls and current developing interstation communication
2026-08-02 local send_accept and accept call handler functions + buzzer and led control
    [main.c]
2026-08-03 chopped down version of main.c with special checker() for Station2.c function & specialized polling + main.c display fixes
    Finished station2.c and main.c
    Station3.c and Station4.c are just variations of station2.c and will be ignored for now
    [Station2.c, main.c]
2026-08-03 bug fixes and rebuilds
    [main.c]
2026-08-05 Fusion & Kicad & (ignore) Kicad Generated BOMs
    [RetroCom Case Bottom.f3d, RetroCom Case Bottom.step, RetroCom Case Bottom.stl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]
2026-08-05 Readme Part 1
    [RetroCom Case Bottom.f3d, RetroCom Case Bottom.step, RetroCom Case Bottom.stl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]
2026-08-06 last minute edit part 1
    [RetroCom.csv, RetroCom.kicad_pcb, RetroCom.kicad_sch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]
2026-08-06 last minute fix part 2
    [RetroCom.kicad_pcb, RetroCom.kicad_sch, RetroCom_Station2.kicad_pcb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]
2026-08-06 assembly instructions 1
2026-08-06 assembly 1fix
2026-08-06 assembly instructions 2
2026-08-06 Case touch up
    [RetroCom Case Top.f3d, RetroCom Case Top.step, RetroCom Case Top.stl]
2026-08-07 BOM & Readme Finished
    [BOM EXCEL.xlsx, BOM.csv]
2026-08-07 gerber files
    [RetroCom-B_Cu.gbr, RetroCom-B_Mask.gbr, RetroCom-B_Paste.gbr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]
